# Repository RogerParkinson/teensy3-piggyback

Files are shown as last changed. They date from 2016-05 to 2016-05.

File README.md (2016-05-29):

# teensy3-piggyback
Piggyback board for a Teensy 3 that holds a MicroSD and a LIPO charger
The LIPO charger needs the connector pads on the Teensy opened to run off battery
The switch allows you to switch from battery supply to USB supply or (central position) off.
The LED shows if it is charging or not.
Pin 14/AO can be queried for a current battery voltage. It is not accurate but it is to scale.
The button on the Teensy is covered by the piggy back board, unless you mount it underneath instead of on top. So the button is replicated on the piggy back.
Developed for Teensy 3.0 but the pins on later Teensys look compatible.
Be aware than the pins on the end opposite the USB are not breadboard friendly (like the pins on the Tennsy). If you solder them in place you won't be able to plug into a breadboard unless you trim the ends of those pins down so they don't plug into your breadboard. The side pins can remain as they are and they will work fine with your breadboard.



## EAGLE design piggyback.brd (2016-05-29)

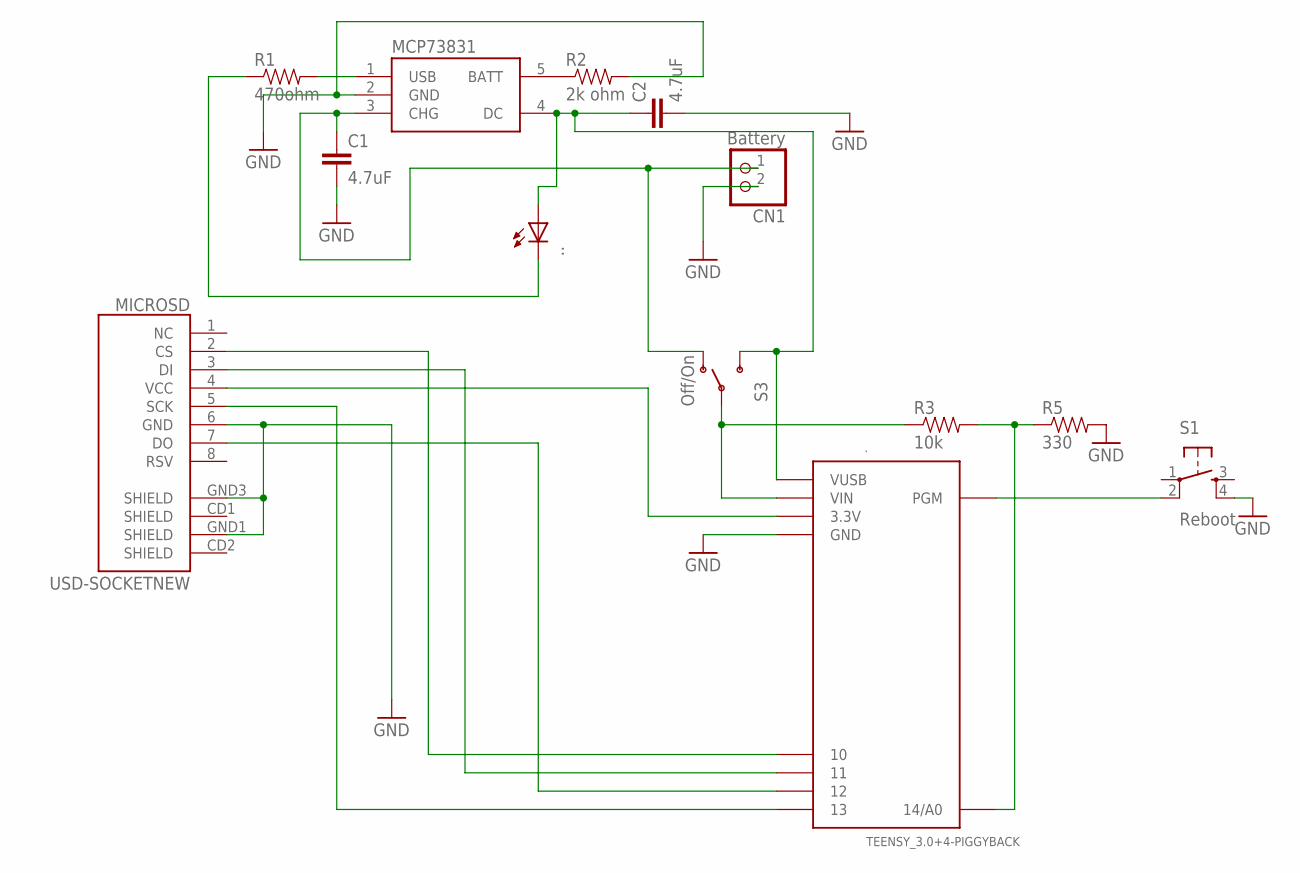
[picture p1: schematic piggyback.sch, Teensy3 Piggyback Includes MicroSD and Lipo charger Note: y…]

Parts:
.: TEENSY_3.0+4-PIGGYBACK
..: LEDCHIP-LED0805; CHIP-LED0805
C1, C2: 4.7uF; 0805
CN1: Battery; JST-PH-2-THM
MCP73831: MAX1555; SOT23-5
MICROSD: USD-SOCKETNEW; MICRO-SD-SOCKET-PP
R1: 470ohm; 0805
R2: 2k ohm; 0805
R3: 10k; 0805
R5: 330; 0805
S1: Reboot; TACTILE_SWITCH_SMD
S3: Off/On; SWITCH-SPST-SMD-A

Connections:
DI: ..11, MICROSD.3 (DI)
DO: ..12, MICROSD.7 (DO)
GND: ..GND1 (GND), C1.2, C2.2, CN1.2 (1), MCP73831.2 (GND), MICROSD.6 (GND), MICROSD.GND1 (SHIELD), MICROSD.GND3 (SHIELD), R2.2, R5.2, S1.4
unnamed: MCP73831.5 (BATT), R2.1
unnamed: C1.1, CN1.1 (2), MCP73831.3 (CHG), S3.1 (O)
unnamed 5: ...C, R1.1; also elsewhere on the board
unnamed: MCP73831.1 (USB), R1.2
unnamed 7: ..VUSB, ...A, C2.1, MCP73831.4 (DC), S3.3 (S); also elsewhere on the board
unnamed: ..PGM, S1.2
unnamed: ..VIN, R3.1, S3.2
unnamed: ..3.3V1 (3.3V), MICROSD.4 (VCC)
unnamed: ..14/A0, R3.2, R5.1
unnamed: ..13, MICROSD.5 (SCK)
unnamed: ..10, MICROSD.2 (CS)

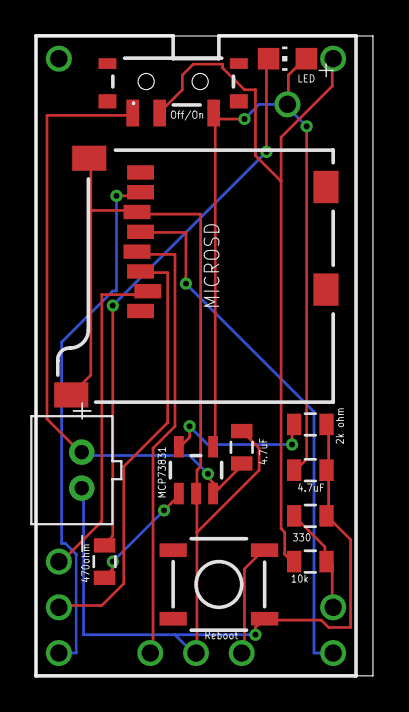
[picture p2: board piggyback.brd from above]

Board: 2 copper layers, 18.7 x 35.5 mm, 13 parts (0 on the bottom side), 14 nets.

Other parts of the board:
LED: LED; CHIP-LED0805

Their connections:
unnamed 5: LED.C; also elsewhere on the board
unnamed 7: LED.A; also elsewhere on the board

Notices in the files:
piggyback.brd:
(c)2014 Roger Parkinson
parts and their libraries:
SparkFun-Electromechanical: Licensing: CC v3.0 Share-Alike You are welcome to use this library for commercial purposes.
